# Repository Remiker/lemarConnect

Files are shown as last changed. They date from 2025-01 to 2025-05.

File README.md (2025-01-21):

# LemarConnect Alguos *(Devloppment phase)*

Lemar Connect is a modular sensor network designed to monitor algae cultivation tanks, developed for the Laboratory Lemar at the IUEM. This project prioritizes long-term autonomy (10 years), modularity, and user-friendliness, while ensuring precise monitoring of environmental parameters such as light intensity, temperature, and humidity.

## Solutions used:

- InfluxDB / MangoDB for data storage
- Grafana for visualization.
- The Things Network / The Things Stack for LoRaWAN communication.
- Arduino IDE for embedded development.

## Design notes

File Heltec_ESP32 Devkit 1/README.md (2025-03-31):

# Devkit Heltec HT-CT62 (Wireless Mini Shell) : ESP32 C3 + SX1262
The HT-CT62 is an ESP32-based module featuring LoRa capabilities powered by the SX1262 chip.

This devkit was designed to simplify LoRa prototyping. The main PCB and sensors are optimized for seamless integration with breadboards, ensuring an easy and efficient prototyping experience. Additionally, we prioritized affordability, keeping the production cost per card under 10€, making it an accessible and cost-effective solution for developers.

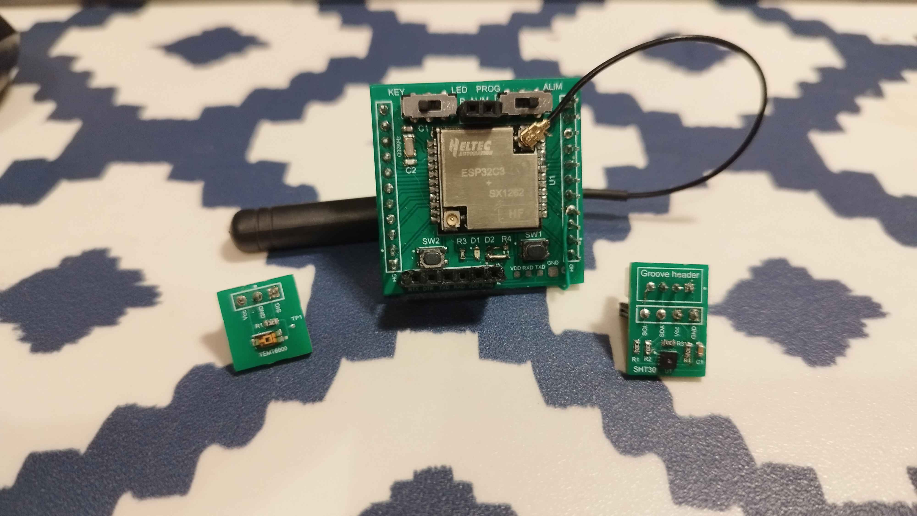
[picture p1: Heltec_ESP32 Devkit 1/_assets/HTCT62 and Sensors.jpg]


## How to run the project
### Hardware :

- A CP2102 programer (or any other type of TTL to UART converter)-
  - Without RTS and DTR : [HiLego - CP2102 ](https://www.amazon.fr/HiLetgo-CP2102-Module-convertisseur-s%C3%A9rie/dp/B00LODGRV8)
  - With RTS and DTR : [USB TTL Module](https://www.amazon.fr/dp/B092ZQ4T9D?ref=ppx_yo2ov_dt_b_fed_asin_title)
- 2 Breadboard clipped on the sides (It doesnt fit on one)
- Any alimentation that can deliver 3.3V and up to 100mA (mabe in the worst condition 150mA, we never came above 100mA)
### Software:
- Arduino IDE
- Install the Heltec Boards and Library see this link : [here](https://docs.heltec.org/en/node/esp32/esp32_general_docs/quick_start.html)
- Install SHT30 Library I modified from Groove Sensor SHT31 Library  :  [Link Here](https://github.com/Seeed-Studio/Grove_SHT31_Temp_Humi_Sensor)  // Added the option of choosing the SDA/SCL pins // Note also that this library works with other board

## Documentation and schematics :
All the schematics and PCB CAD are made on Altium Designer, be carefull some parte of the documentation might be in french

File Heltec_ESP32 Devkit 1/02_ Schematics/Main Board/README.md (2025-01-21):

# Design issues and fixes :
* GPIO9 must be connected to UserKey: You can add a wire between Switch S2 common and GPIO9 :

* Put the switch only in alim mode and remove the resistor and the LED framed in RED 

<b>All of these issue will be updates in a future version  </b>

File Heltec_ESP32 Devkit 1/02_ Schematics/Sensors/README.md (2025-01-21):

# Design issues and fixes :
## SHT30 :
On the SHT30, there's a series resistor between SDA and SCL instead of a pull-up resistor. The sensor therefore works at first, but eventually stops working. 

You also have to be careful when soldering the SHT: if you put flux in the sensor or heat it too long, the sensor won't work.

<b>This will be updated in the next version <b>

## TEMT6000:
No issues found on this PCB

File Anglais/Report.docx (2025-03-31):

LemarConnect Alguos

The objective of this project is to surveillance the growth of seaweed in a controlled climate, where scientists analyze and observe them while adding or adjusting the environment. So for this project we had to develop a system that helps the scientists to be able to measure the temperature, light and the humidity inside the room or inside a specific container. We are a group of 4, this project includes a hardware development and software development, so we devised ourselves to work better in pairs, a team works on the hardware part and the other on the software part.

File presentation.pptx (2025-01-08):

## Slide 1

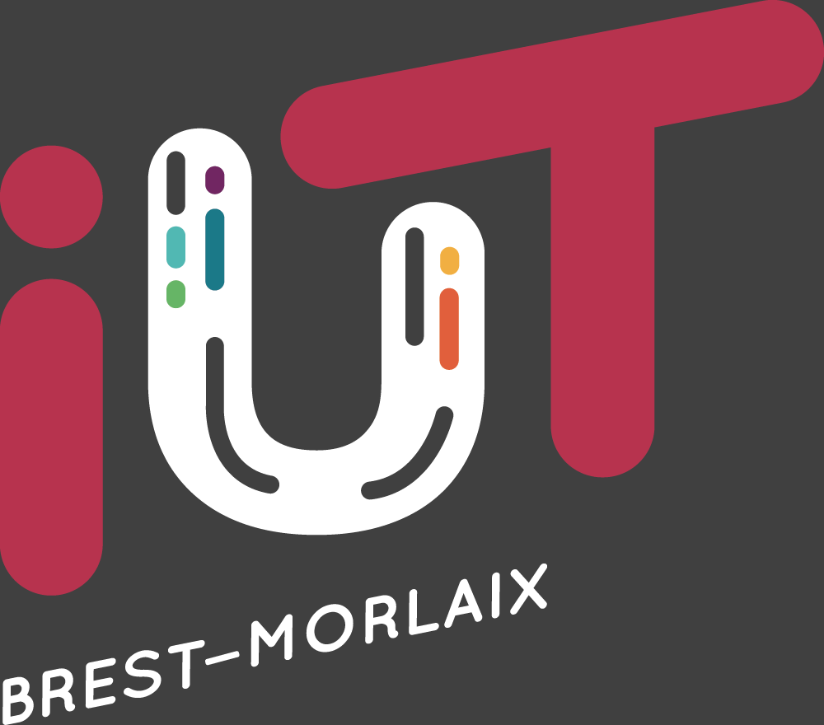
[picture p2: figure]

Etudiant : Jad SFEIR

2024-2025

GEII

Système informatique

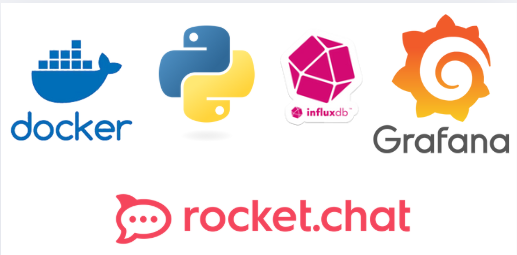
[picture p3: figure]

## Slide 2

Jad SFEIR – SAE

Plan de l’exposé
- Introduction
- Explication pour :
  - Docker
  - Python
  - InfluxDB
  - Grafana
  - Rocket Chat
- Conclusion

2

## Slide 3

Introduction

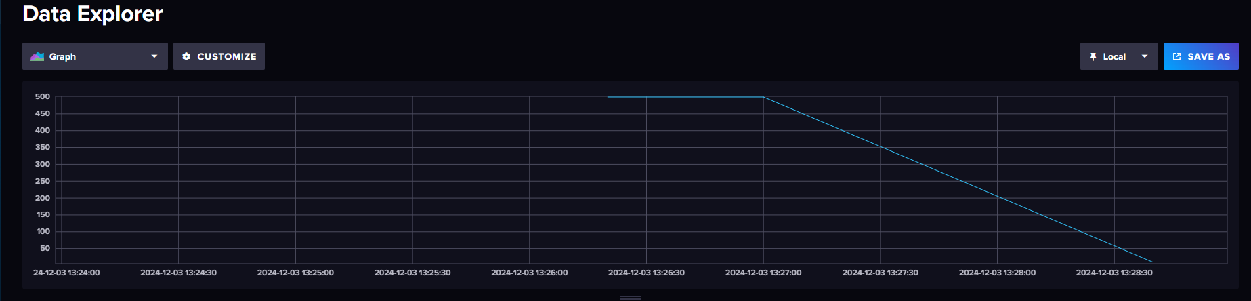
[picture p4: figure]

  - Python
  - Docker
  - InfluxDB
  - Grafana
  - Rocket Chat

InfluxDB

3

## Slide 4

Docker

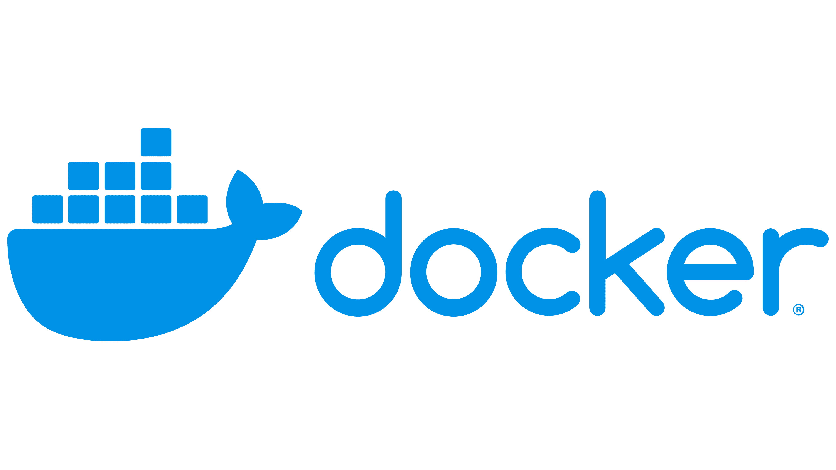
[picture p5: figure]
Docker Logo : histoire, signification de l'emblème

C’est quoi Docker?
Pourquoi utiliser Docker?
Quel est l'avantage principal de Docker ?

4

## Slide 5

Docker

C’est quoi Docker-container, docker image?
C’est quoi la différence entre Docker et machine virtuel?

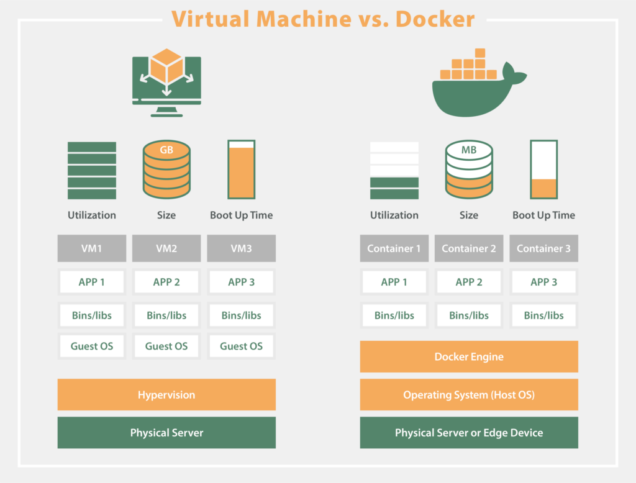
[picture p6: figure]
Comparison Docker and virtual machines_OPC Router

5

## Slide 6

Python

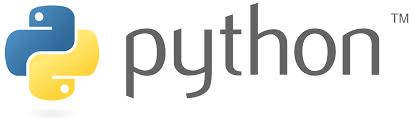
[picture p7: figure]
Fichier:Python logo and wordmark.svg — Wikipédia

Pourquoi utiliser python?
Quelles sont les fonctions de python dans le système ?

6

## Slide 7

InfluxDB

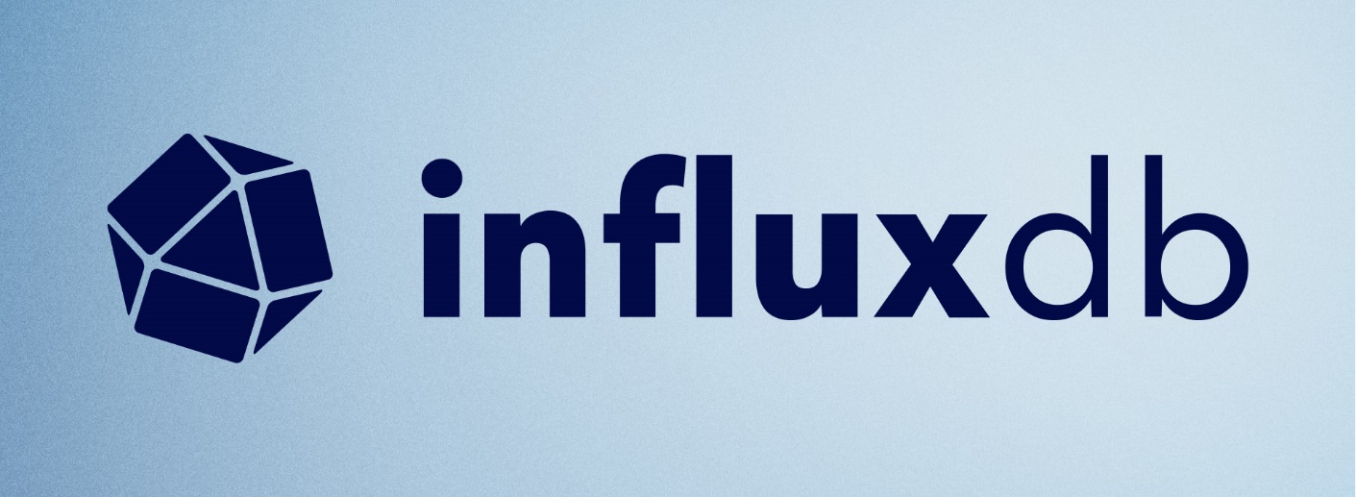
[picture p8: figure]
Influx database development company | Influxdb development services

C’est quoi influxdb?
Pourquoi utiliser influxdb?

7

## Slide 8

Grafana

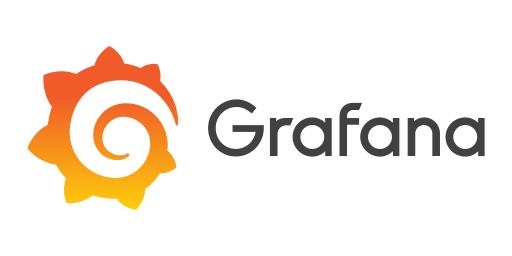
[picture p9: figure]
Grafana logo - Icônes Médias sociaux et logos

C’est quoi grafana?
Pourquoi utiliser grafana?

8

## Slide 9

Rocket Chat

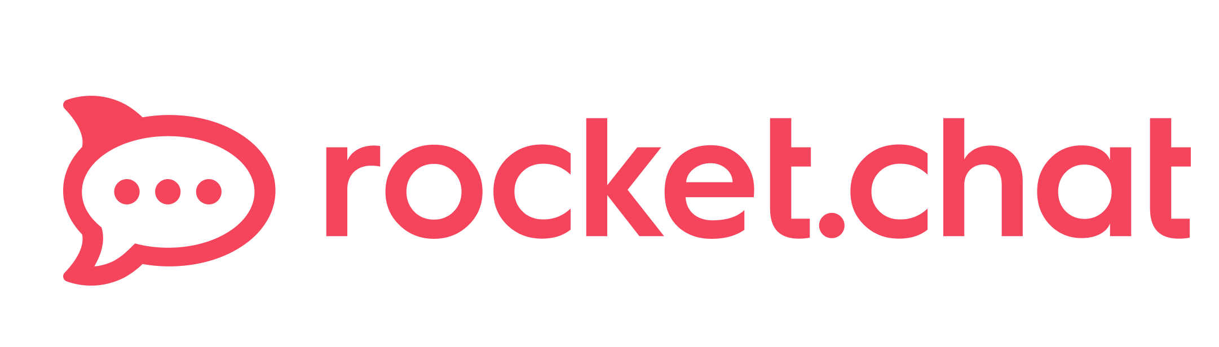
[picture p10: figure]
Rocket.Chat Customer Reviews 2024 | SoftwareReviews

C’est quoi rocket chat?
Pourquoi utiliser rocket chat?

9

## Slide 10

Conclusion

Fonctionne

En cours

Ne fonctionne pas

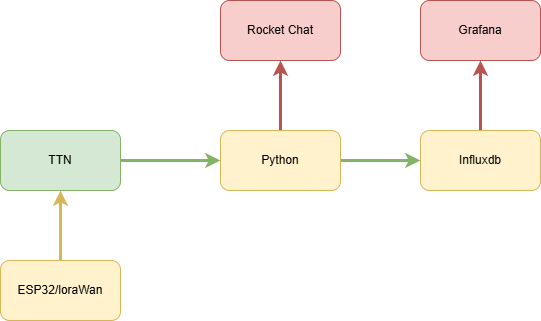
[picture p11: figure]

10

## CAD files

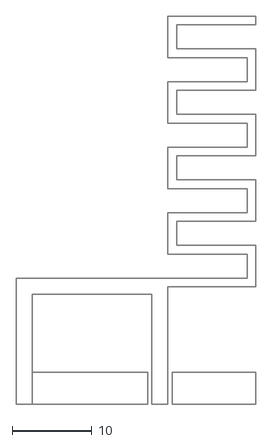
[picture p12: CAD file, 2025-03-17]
Heltec_ESP32 Devkit 1/02_ Schematics/PCB_SX126x_ANTENNA/antenna.dxf
30.0 x 48.5

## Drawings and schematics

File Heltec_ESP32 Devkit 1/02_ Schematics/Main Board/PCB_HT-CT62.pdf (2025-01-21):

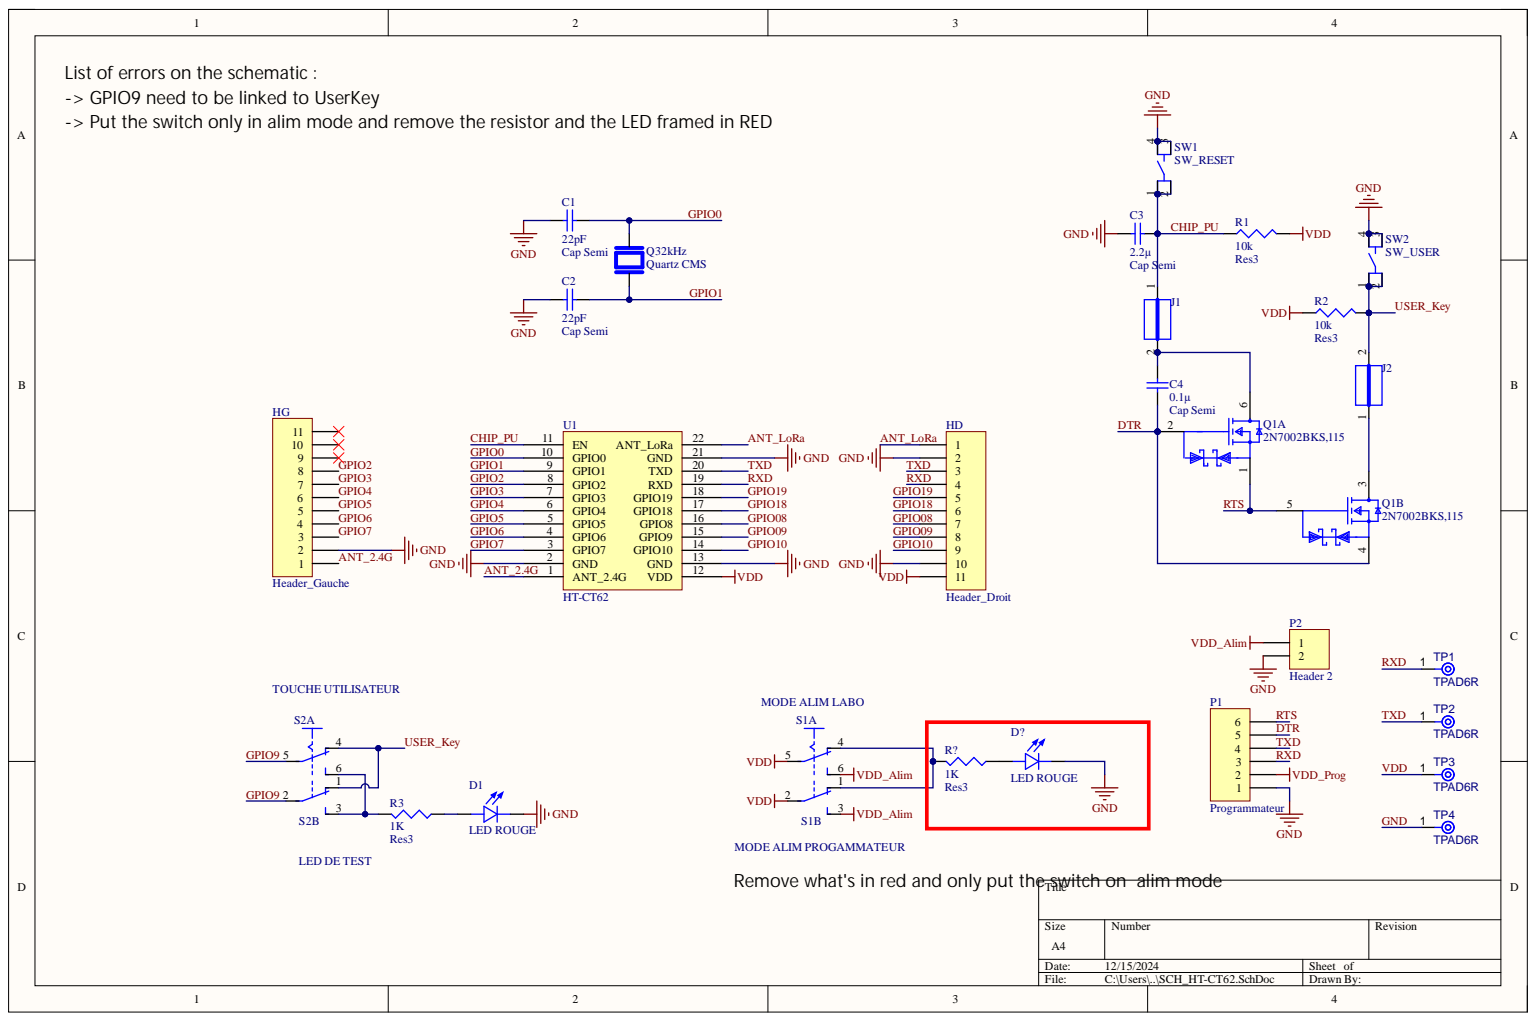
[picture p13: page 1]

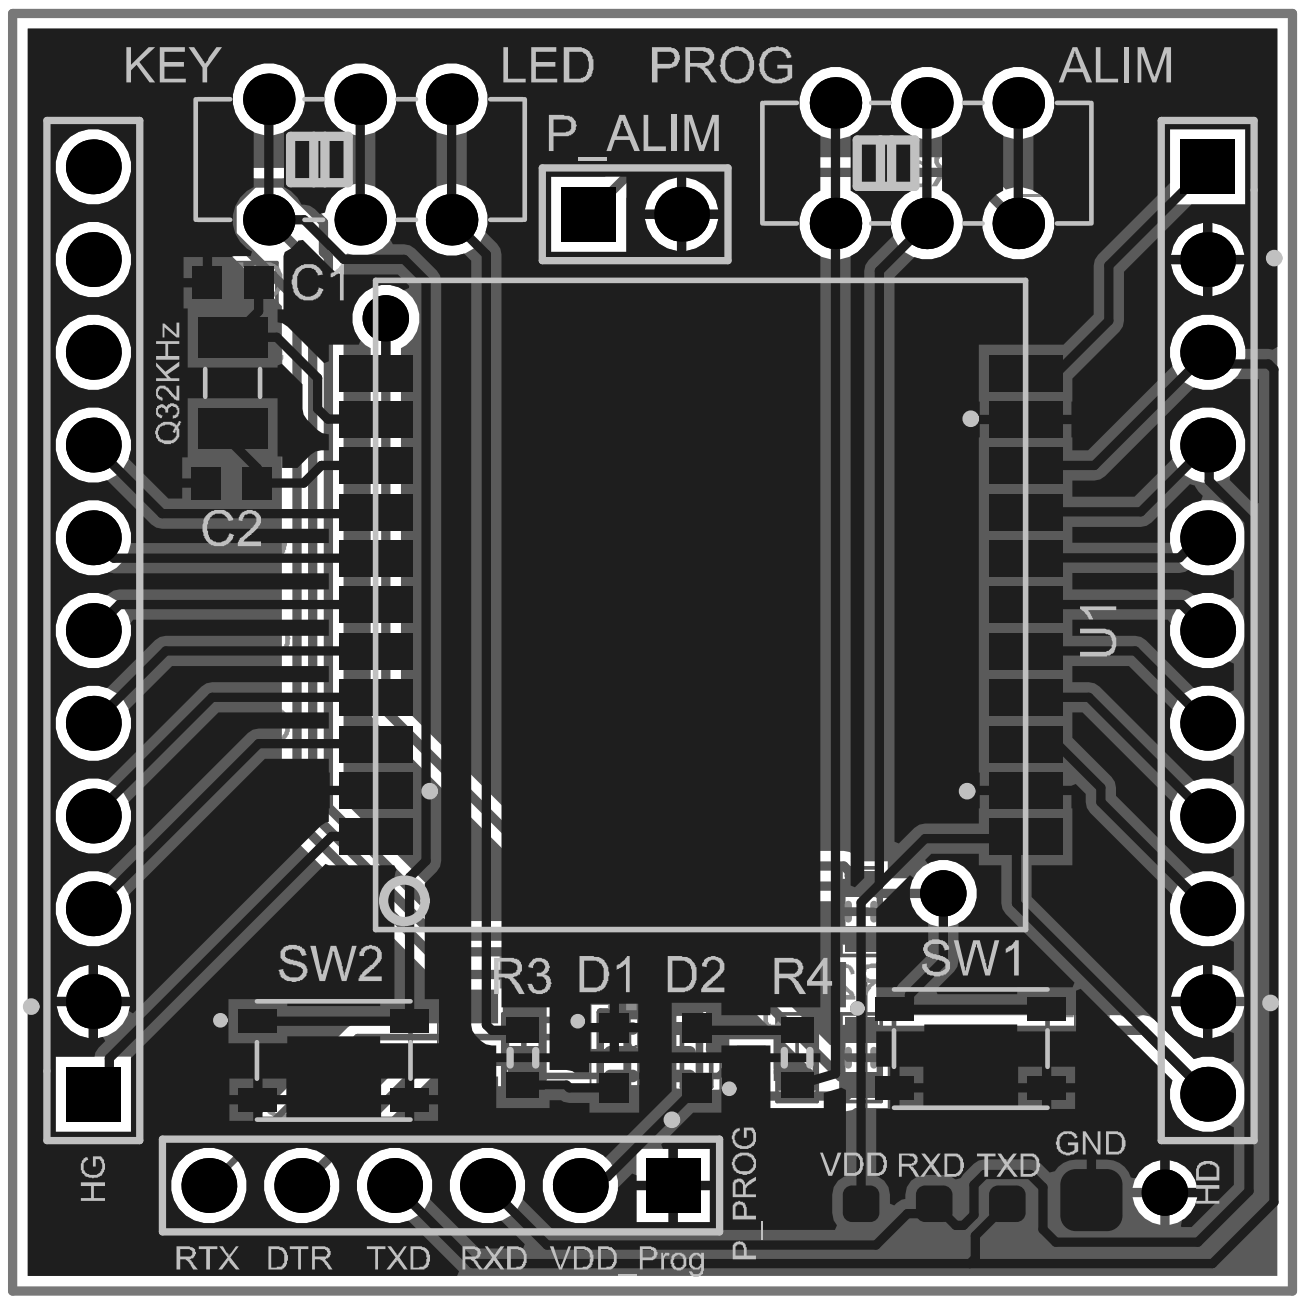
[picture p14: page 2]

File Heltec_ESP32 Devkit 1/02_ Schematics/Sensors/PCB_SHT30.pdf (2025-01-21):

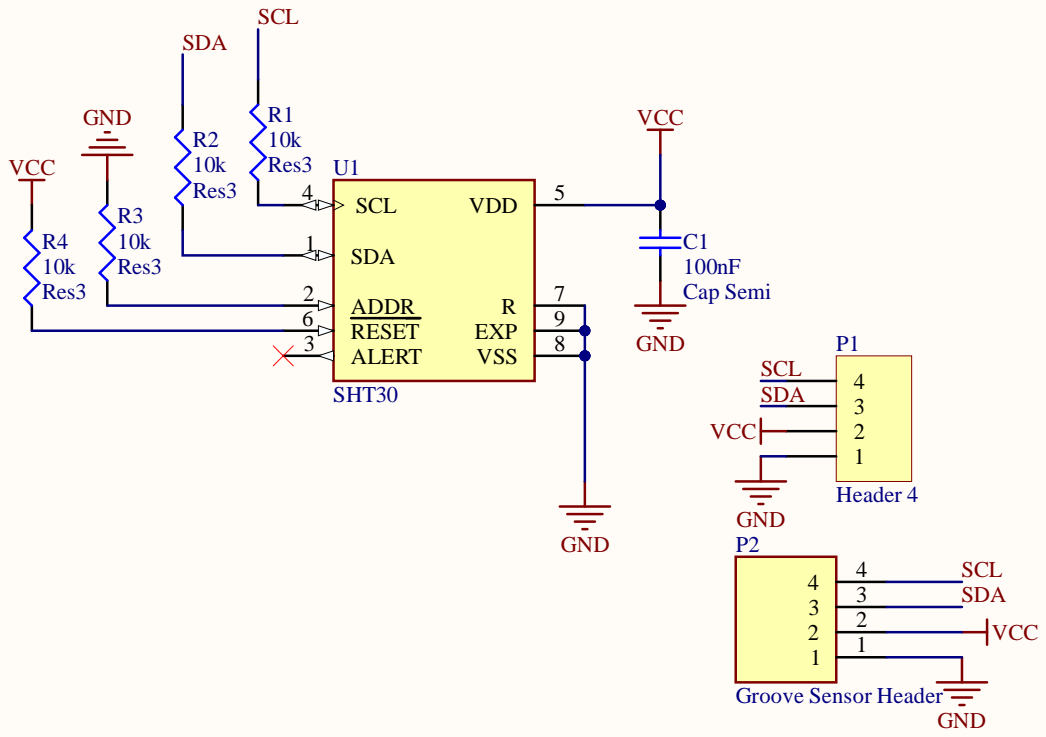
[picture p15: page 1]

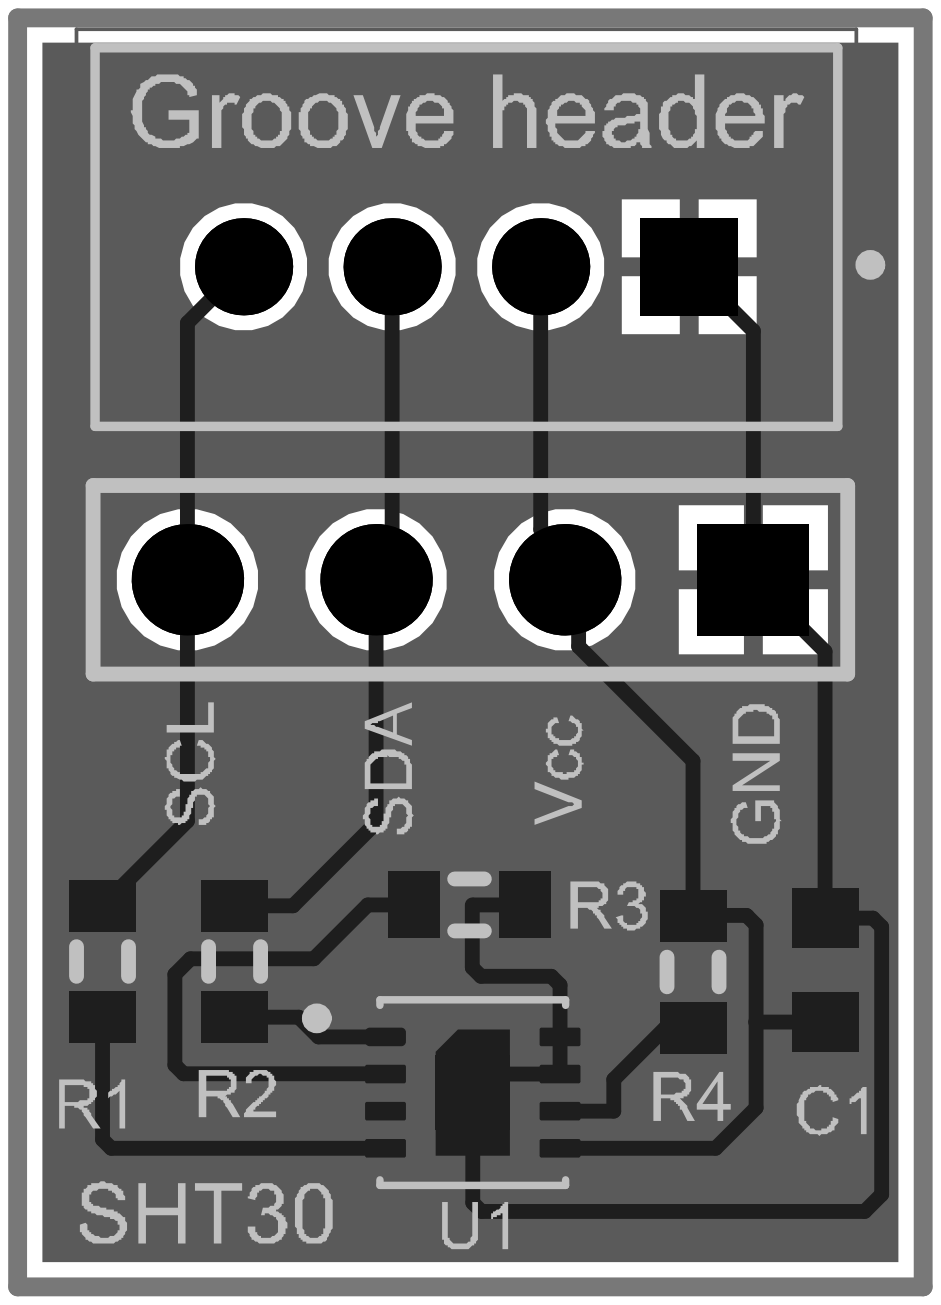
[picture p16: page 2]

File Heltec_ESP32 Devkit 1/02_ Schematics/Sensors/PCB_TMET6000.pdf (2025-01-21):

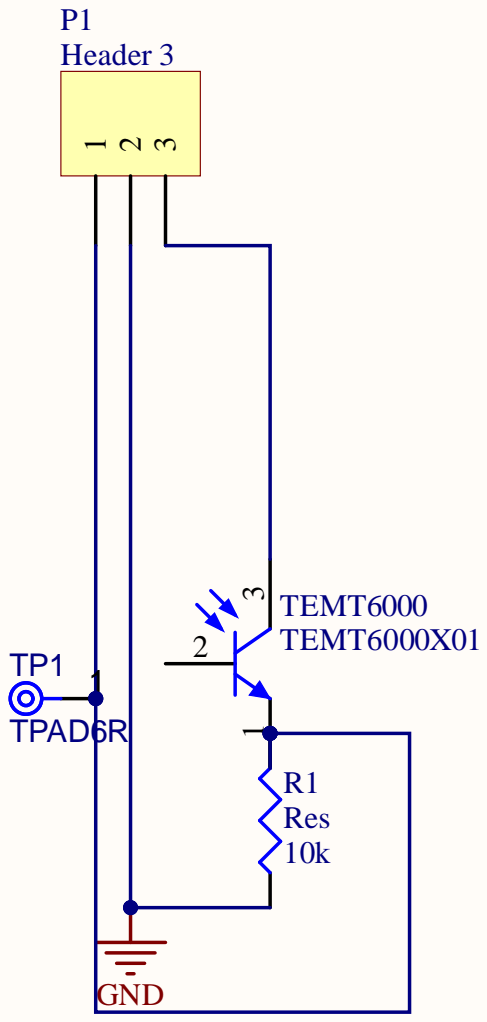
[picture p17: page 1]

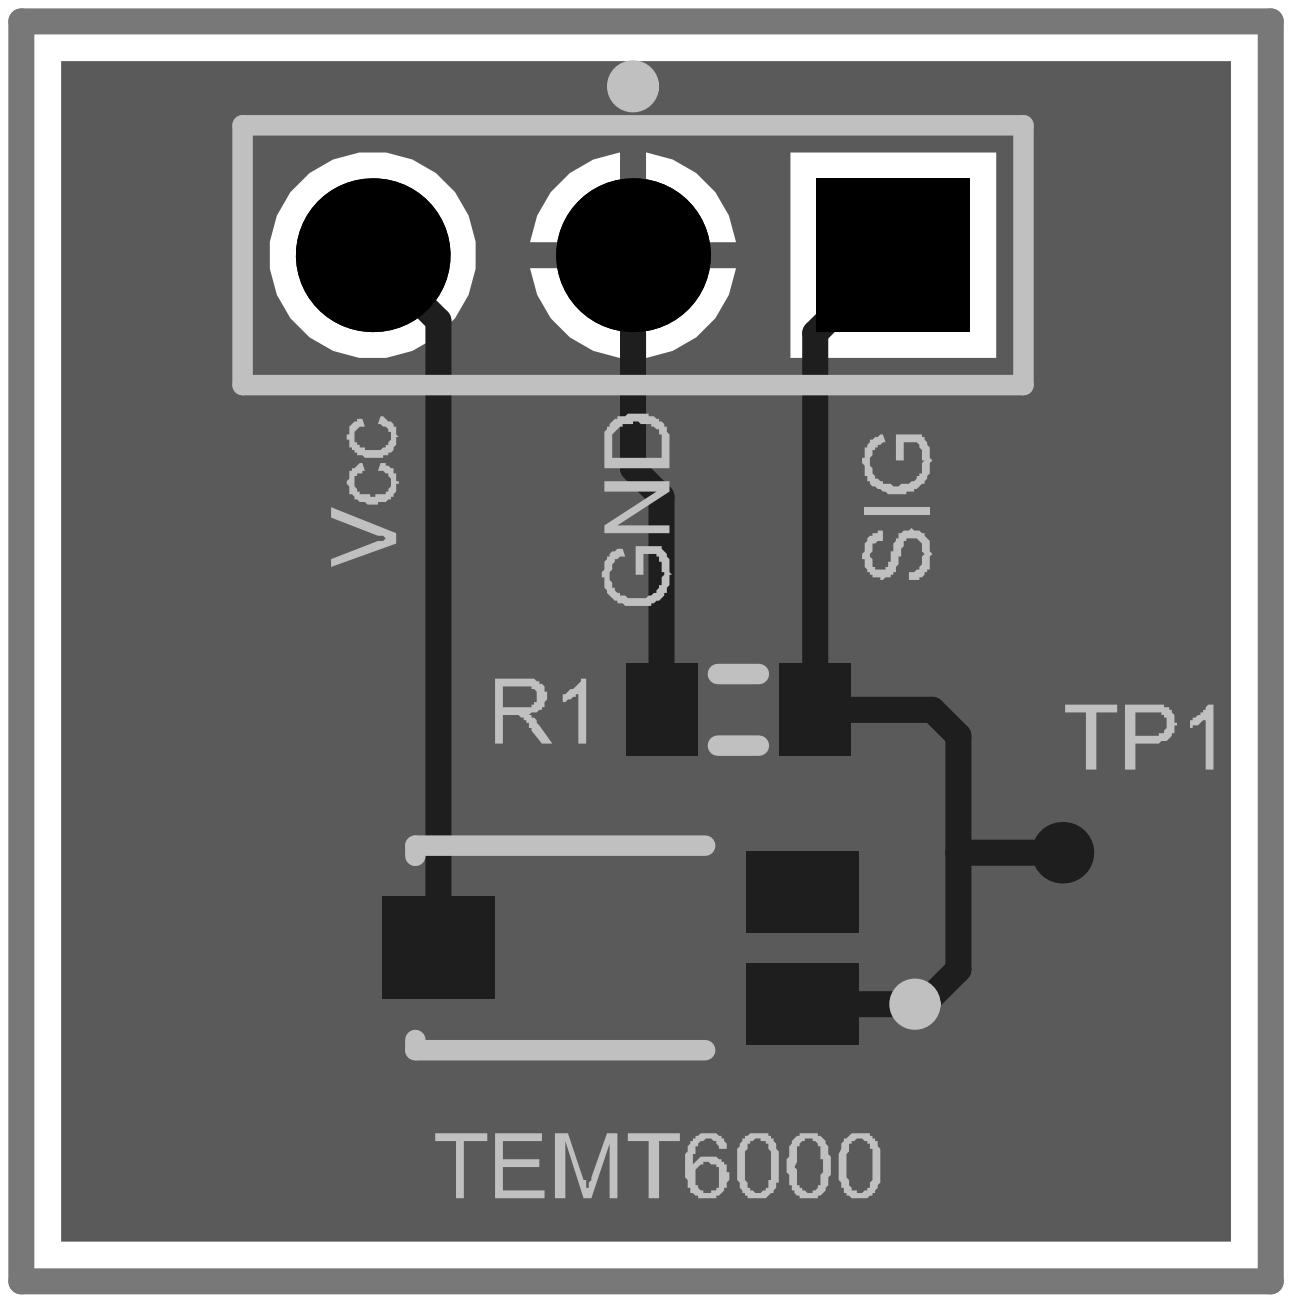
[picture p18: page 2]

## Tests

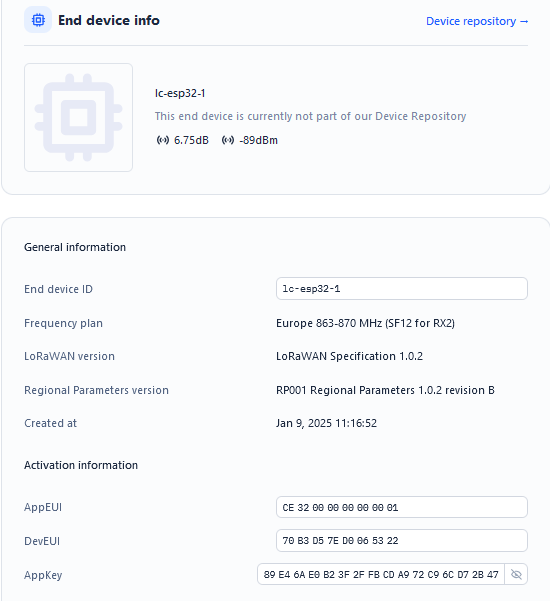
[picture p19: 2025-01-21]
Heltec_ESP32 Devkit 1/00_Unitary_test/device config.png

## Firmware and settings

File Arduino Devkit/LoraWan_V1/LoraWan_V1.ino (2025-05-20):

#include <MKRWAN.h>
#include <Arduino_MKRENV.h>
#include <LoRa.h>

// Uncomment if using the Murata chip as a module
// LoRaModem modem(Serial1);

#include "arduino_secrets.h"
LoRaModem modem;
#define LORA_DELAY 3000
// Please enter your sensitive data in the Secret tab or arduino_secrets.h
String appEui = SECRET_APP_EUI;
String appKey = SECRET_APP_KEY;
int waitToSendMessage = 0;
int enableDebug = 1;

void setup()
{
  // Setting up serial
  Serial.begin(115200);

  // Setting up RF Band
  if (!modem.begin(EU868))
  {
    Serial.println("Failed to start module");
    while (1)
    {
    }
  };

  // Info on Module
  Serial.print("Your module version is: ");
  Serial.println(modem.version());
  Serial.print("Your device EUI is: ");
  Serial.println(modem.deviceEUI());

  // OTAA connection
  int connected = modem.joinOTAA(appEui, appKey);
  if (!connected)
  {
    Serial.print("Your module version is: ");
  Serial.println(modem.version());
  Serial.print("Your device EUI is: ");
  Serial.println(modem.deviceEUI());
    while (!connected)
    {
      Serial.println("Something went wrong; are you indoor? Move near a window and retry");
      Serial.println("Retrying...");
      connected = modem.joinOTAA(appEui, appKey);
      delay(1000);
    }
  }

  // Set poll interval to 60 secs.
  modem.minPollInterval(60);
  // NOTE: independent of this setting, the modem will
  // not allow sending more than one message every 2 minutes,
  // this is enforced by firmware and can not be changed.

  if (!ENV.begin())
  {
    Serial.println("Failed to initialize MKR ENV shield!");
    while (1)
      ;
  }
  waitToSendMessage = millis();
}
uint16_t temperature;
  uint16_t humidity ;
  uint16_t pressure;
  uint16_t illuminance ;
   uint8_t buffer[8];
void loop()
{
 
  //// Get data from sensors
   temperature = ENV.readTemperature() * 100;
   humidity = ENV.readHumidity() * 100;
   pressure = ENV.readPressure() * 100;
   illuminance = ENV.readIlluminance() * 100;
  ////////////////////////
  ///// Store Data in Buffer
  buffer[0] = byte(temperature >> 8);
  buffer[1] = byte(temperature & 0x00FF);
  buffer[2] = byte(humidity >> 8);
  buffer[3] = byte(humidity & 0x00FF);
  buffer[4] = byte(pressure >> 8);
  buffer[5] = byte(pressure & 0x00FF);
  buffer[6] = byte(illuminance >> 8);
  buffer[7] = byte(illuminance & 0x00FF);
  ////////////////////////////////////

  /////////////// Data Debug
  if (enableDebug)
  {
    //Serial.print("Temperature : ");
    //Serial.println(ENV.readTemperature());

    //Serial.print("Humidity : ");
    //Serial.println(ENV.readHumidity());

    //Serial.print("Pressure : ");
    //Serial.println(ENV.readPressure());
for(int x;x<8;x++)
{
  illuminance += ENV.readIlluminance() * 100;
}
illuminance = illuminance/9;
    Serial.print("Illuminance : ");
    Serial.println(illuminance/100);
  }

  ///////////// send data to TTN
  if (millis() - waitToSendMessage > LORA_DELAY)
  {
    waitToSendMessage = millis();
    modem.beginPacket();
    modem.write(buffer, 8);
    int err;
    err = modem.endPacket(true);
    if (enableDebug)
    {
      if (err > 0)
      {
        Serial.println("Message sent correctly!");
      }
      else
      {
        Serial.println("Error sending message :(");
        Serial.println("(you may send a limited amount of messages per minute, depending on the signal strength");
        Serial.println("it may vary from 1 message every couple of seconds to 1 message every minute)");
      }
    }
    if (!modem.available())
    {
      Serial.println("No downlink message received at this time.");
      return;
    }
  }
  /////////////////////////////////
}

void sendMessage()
{
  Serial.println("Enter a message to send to network");
  Serial.println("(make sure that end-of-line 'NL' is enabled)");

  while (!Serial.available())
    ;
  String msg = "";

  Serial.print("Sending: " + msg + " - ");
  for (unsigned int i = 0; i < msg.length(); i++)
  {
    Serial.print(msg[i] >> 4, HEX);
    Serial.print(msg[i] & 0xF, HEX);
    Serial.print(" ");
  }
}

void recieveMessage()
{
  char rcv[64];
  int i = 0;
  while (modem.available())
  {
    rcv[i++] = (char)modem.read();
  }
  Serial.print("Received: ");
  for (unsigned int j = 0; j < i; j++)
  {
    Serial.print(rcv[j] >> 4, HEX);
    Serial.print(rcv[j] & 0xF, HEX);
    Serial.print(" ");
  }
}

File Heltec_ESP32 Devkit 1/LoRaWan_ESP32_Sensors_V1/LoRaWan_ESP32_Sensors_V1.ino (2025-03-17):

/* Heltec Automation LoRaWAN communication example
 *
 * Function:
 * 1. Upload node data to the server using the standard LoRaWAN protocol.
 *  
 * Description:
 * 1. Communicate using LoRaWAN protocol.
 * 
 * HelTec AutoMation, Chengdu, China
 * 成都惠利特自动化科技有限公司
 * www.heltec.org
 *
 * */

#include "LoRaWan_APP.h"

#include <SHT30.h>
#define I2C_SDA 18
#define I2C_SCL 19
#define LIGHTSENSOR_PIN 2

SHT30 sht30 = SHT30();
/* OTAA para*/
uint8_t devEui[] = { 0x70, 0xB3, 0xD5, 0x7E, 0xD0, 0x06, 0x53, 0x22 };
uint8_t appEui[] = { 0xCE, 0x32, 0x00, 0x00, 0x00, 0x00, 0x00, 0x01 };
uint8_t appKey[] = { 0x89, 0xE4, 0x6A, 0xE0, 0xB2, 0x3F, 0x2F, 0xFB, 0xCD, 0xA9, 0x72, 0xC9, 0x6C, 0xD7, 0x2B, 0x47 };

/* ABP para*/
uint8_t nwkSKey[] = { 0x15, 0xb1, 0xd0, 0xef, 0xa4, 0x63, 0xdf, 0xbe, 0x3d, 0x11, 0x18, 0x1e, 0x1e, 0xc7, 0xda, 0x85 };
uint8_t appSKey[] = { 0xd7, 0x2c, 0x78, 0x75, 0x8c, 0xdc, 0xca, 0xbf, 0x55, 0xee, 0x4a, 0x77, 0x8d, 0x16, 0xef, 0x67 };
uint32_t devAddr = (uint32_t)0x007e6ae1;

/*LoraWan channelsmask, default channels 0-7*/
uint16_t userChannelsMask[6] = { 0x00FF, 0x0000, 0x0000, 0x0000, 0x0000, 0x0000 };

/*LoraWan region, select in arduino IDE tools*/
LoRaMacRegion_t loraWanRegion = ACTIVE_REGION;

/*LoraWan Class, Class A and Class C are supported*/
DeviceClass_t loraWanClass = CLASS_A;

/*the application data transmission duty cycle.  value in [ms].*/
uint32_t appTxDutyCycle = 60000;

/*OTAA or ABP*/
bool overTheAirActivation = true;

/*ADR enable*/
bool loraWanAdr = true;

/* Indicates if the node is sending confirmed or unconfirmed messages */
bool isTxConfirmed = true;

/* Application port */
uint8_t appPort = 2;
/*!
* Number of trials to transmit the frame, if the LoRaMAC layer did not
* receive an acknowledgment. The MAC performs a datarate adaptation,
* according to the LoRaWAN Specification V1.0.2, chapter 18.4, according
* to the following table:
*
* Transmission nb | Data Rate
* ----------------|-----------
* 1 (first)       | DR
* 2               | DR
* 3               | max(DR-1,0)
* 4               | max(DR-1,0)
* 5               | max(DR-2,0)
* 6               | max(DR-2,0)
* 7               | max(DR-3,0)
* 8               | max(DR-3,0)
*
* Note, that if NbTrials is set to 1 or 2, the MAC will not decrease
* the datarate, in case the LoRaMAC layer did not receive an acknowledgment
*/
uint8_t confirmedNbTrials = 4;

/* Prepares the payload of the frame */
static void prepareTxFrame(uint8_t port) {
  /*appData size is LORAWAN_APP_DATA_MAX_SIZE which is defined in "commissioning.h".
  *appDataSize max value is LORAWAN_APP_DATA_MAX_SIZE.
  *if enabled AT, don't modify LORAWAN_APP_DATA_MAX_SIZE, it may cause system hanging or failure.
  *if disabled AT, LORAWAN_APP_DATA_MAX_SIZE can be modified, the max value is reference to lorawan region and SF.
  *for example, if use REGION_CN470, 
  *the max value for different DR can be found in MaxPayloadOfDatarateCN470 refer to DataratesCN470 and BandwidthsCN470 in "RegionCN470.h".
  */

  sht30.begin(I2C_SDA, I2C_SCL);

  uint16_t temp = sht30.getTemperature()*100;
  uint16_t hum = sht30.getHumidity()*100;
  uint16_t lum =readIlluminance(LIGHTSENSOR_PIN)*100;

  // Serial printing
  Serial.print("Temp = ");
  Serial.print(temp);
  Serial.println(" C");  //The unit for  Celsius because original arduino don't support speical symbols
  Serial.print("Hum = ");
  Serial.print(hum);
  Serial.println("%");
  Serial.print("Lum = ");
  Serial.print(lum);
  Serial.println(" lux");
  Serial.println();

  appDataSize = 6;
  appData[0] = byte(temp >> 8);
  appData[1] = byte(temp & 0x00FF);
  appData[2] = byte(hum >> 8);
  appData[3] = byte(hum & 0x00FF);
  appData[4] = byte(lum >> 8);
  appData[5] = byte(lum & 0x00FF);

}

//if true, next uplink will add MOTE_MAC_DEVICE_TIME_REQ


void setup() {
  Serial.begin(115200);
  Mcu.begin(HELTEC_BOARD, SLOW_CLK_TPYE);
}

void loop() {
  switch (deviceState) {
    case DEVICE_STATE_INIT:
      {
#if (LORAWAN_DEVEUI_AUTO)
        LoRaWAN.generateDeveuiByChipID();
#endif
        LoRaWAN.init(loraWanClass, loraWanRegion);
        //both set join DR and DR when ADR off
        LoRaWAN.setDefaultDR(3);
        break;
      }
    case DEVICE_STATE_JOIN:
      {
        LoRaWAN.join();
        break;
      }
    case DEVICE_STATE_SEND:
      {
        prepareTxFrame(appPort);
        LoRaWAN.send();

        deviceState = DEVICE_STATE_CYCLE;

        break;
      }
    case DEVICE_STATE_CYCLE:
      {
        // Schedule next packet transmission
        txDutyCycleTime = appTxDutyCycle + randr(-APP_TX_DUTYCYCLE_RND, APP_TX_DUTYCYCLE_RND);
        LoRaWAN.cycle(txDutyCycleTime);
        deviceState = DEVICE_STATE_SLEEP;
        break;
      }
    case DEVICE_STATE_SLEEP:
      {
        LoRaWAN.sleep(loraWanClass);
        break;
      }
    default:
      {
        deviceState = DEVICE_STATE_INIT;
        break;
      }
  }
}


float readIlluminance(uint pin) {
  // read analog value and convert to mV
  float mV = (analogRead(pin) * 3300.0) / 1023.0;

  // 5 mV per lux
  float reading = (mV / 5.0);  // Readings are in lux scale

  return reading;  // 1 lux = 1 meter-candle
}

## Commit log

2024-09-11 fixed arduino_secrets.h place
2024-09-11 Reduced temperature data sent
2024-09-11 cleared project and fixed bug on mask on LoRaWAN_V1 and added unitary test
    [00_ReadSensors.ino, LoraWan_V1.ino]
2024-09-12 All data are being sent correctly with small bug to be fixed
    [LoraWan_V1.ino]
2024-09-12 added Serial print for all the datas
2024-09-12 removed delays and added Millis, the code no longer stops
    [LoraWan_V1.ino]
2025-01-21 Added all about Devkit
    [PCB_SHT30.DRL, PCB_SHT30.GBL, PCB_SHT30.GBO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]
2025-03-17 working on atenna + docker
    [Antenne.PcbDoc, PCB_SX126x_ANTENNA.PrjPcb, PCB_SX126x_Antenna.PcbDoc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]
2025-03-31 up to date
    [PCB_SX126x_Antenna.PcbDoc]
